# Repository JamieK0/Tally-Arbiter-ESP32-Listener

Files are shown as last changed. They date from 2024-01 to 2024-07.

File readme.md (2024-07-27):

# ESP32 Listener/Tally Light with OLED and Neopixels
An ESP32 listener for Tally Arbiter.
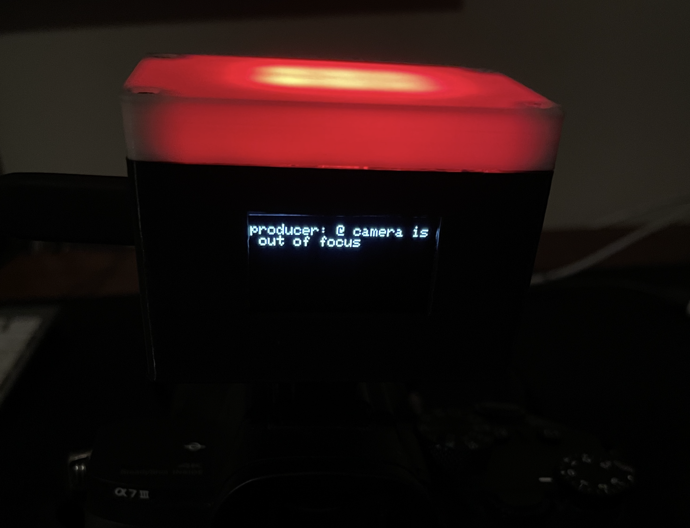
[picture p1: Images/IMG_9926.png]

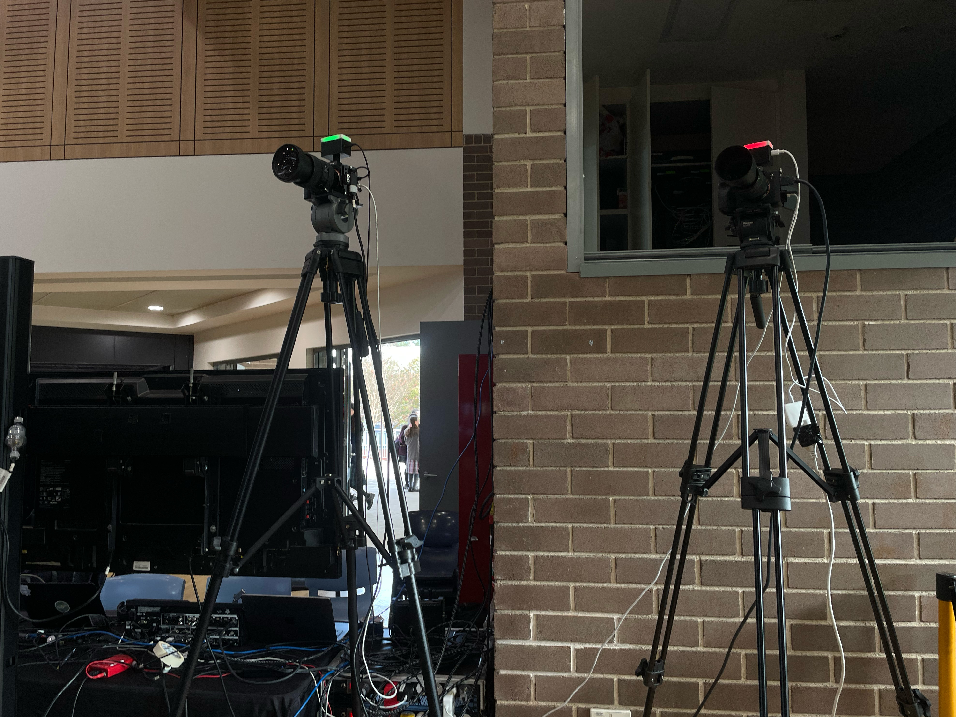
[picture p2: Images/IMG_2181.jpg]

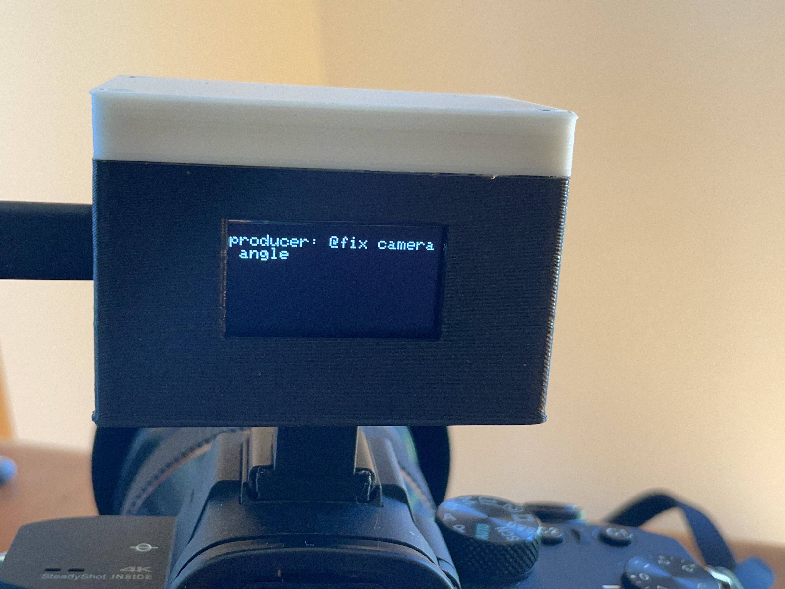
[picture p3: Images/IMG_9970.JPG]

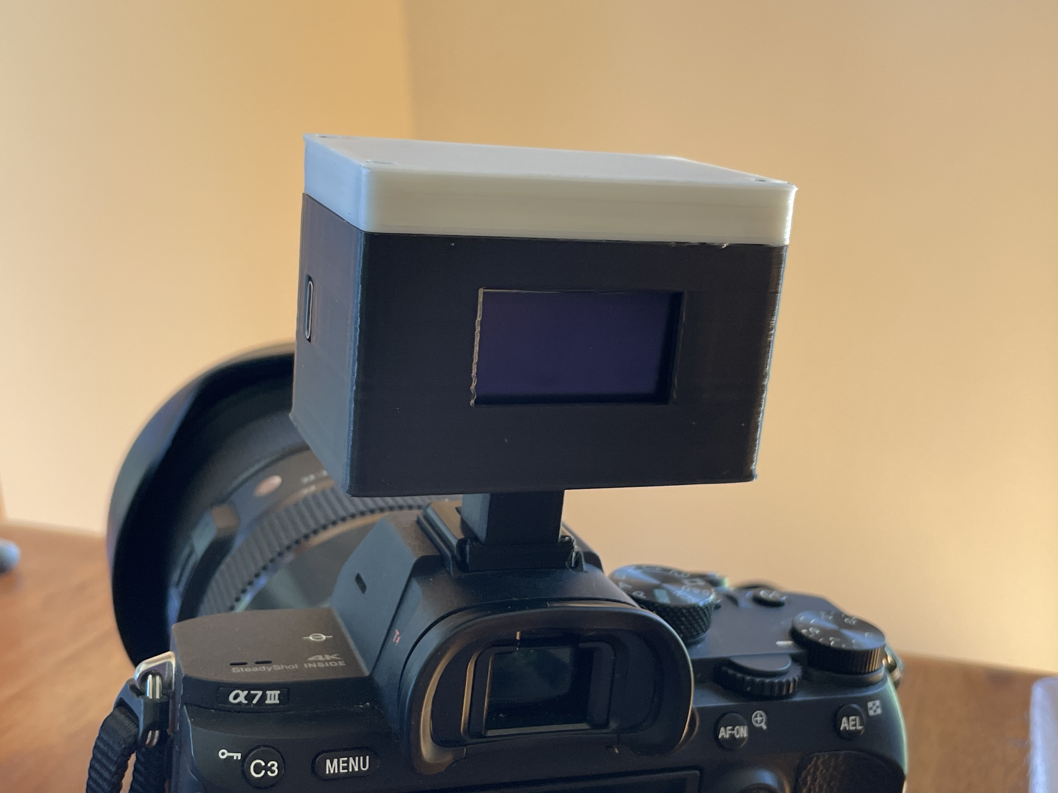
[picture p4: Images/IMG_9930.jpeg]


## Features
- Neopixel indicator lights for program and preview
- OLED screen for displaying messages
- Messages are sent to the OLED screen on the tally light unit by including "@" at the start of the message
- 3D printed case. CAD files are included
- Side and bottom attachment points for accessories. Coldshoe mount is included in the CAD files.

## Tally Arbiter

> A camera tally lights project capable of listening/fetching tally data from multiple sources or video switchers and arbitrating whether an end device is considered to be in Preview or Program. Supports many different switcher types and protocols as well as many types of tally output.

Learn more [here](https://github.com/josephdadams/TallyArbiter).

## Bill of materials
- ESP32 development board
- 1.3 inch i2c OLED screen
- 6x neopixel LEDs
- 14x M3 4mm length (OD 4.5mm) heated inserts
- 6x M3 16mm hex socket grubscrews
- Black PLA filament
- White PLA filament
- Insulated copper wires

## Tools
- 3D printer
- Soldering iron
- Hot glue gun
- Hex key set

## Installation

### 3D Printing
Use the seperate 3mf files in the CAD folder for printing.
I printed my case in PLA and it has been working fine.
The top piece is to be printed in white to act as diffusion for the LEDs.
#### Recommended print settings
- 3 permiters
- 15% infill for the bottom piece
- No infill or solid infill for the top piece. This is to ensure the LED diffusion is smooth.
- The coldshoe mount should be printed with the tally connector face facing the built plate. Supports may be needed.

### Wiring
| ESP32 | OLED | Neopixels |
|---|---|---|
| 3V | VCC  | 5V |
| GND | GND  | GND |
| D18 | | DIN |
| D21 | SCA  | |
| D22 | SCK  | |

### Programing the ESP32
Use the Ardunio IDE to program the ESP32. This [tutorial](https://randomnerdtutorials.com/installing-the-esp32-board-in-arduino-ide-windows-instructions/) is helpful for installing ESP32 boards in the IDE.
The Arduino IDE sketch file is in the esp32-neopixel-listener folder.

### Building the case
Use a soldering iron to melt the heated inserts into the holes in between the two parts of the case. Add heated inserts to the accessory attachment points as well.
The screen can be placed into its compartment. Use some hot glue to secure it in place if necessary.
The ESP32 can slide in on an angle before being pushed against the back of the case to hold it in place.
The neopixels sit above the ESP32.
Use the appropriately sized hex key to screw the grub screws into the heated inserts, attaching the two pieces of the case.

## Making your own accessories
Accessories can be connected using this template for the heated inserts alignment:
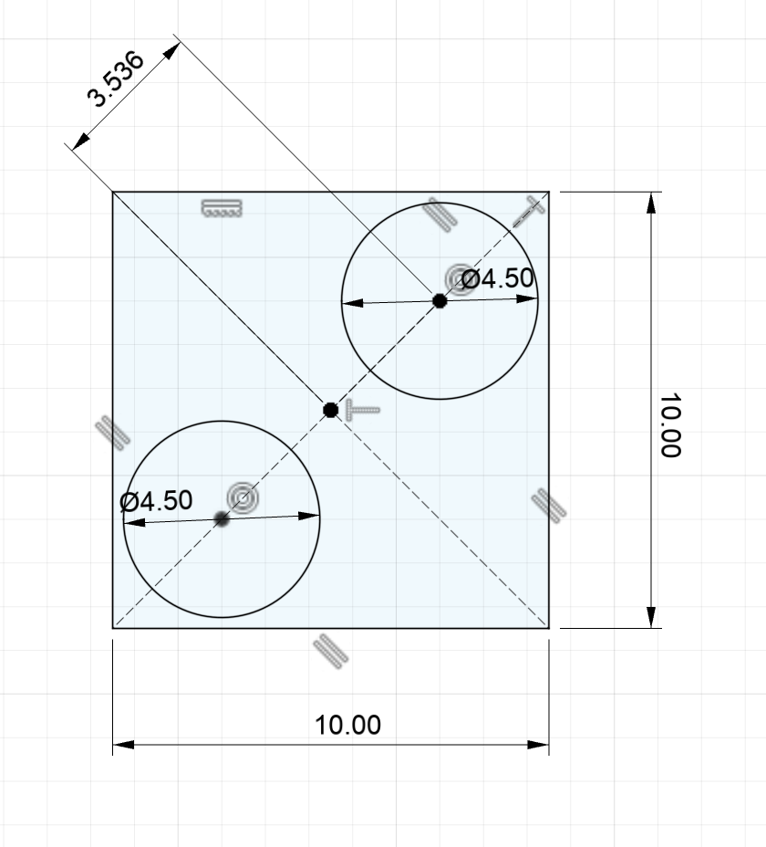
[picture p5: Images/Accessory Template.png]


## License
Distributed under the MIT License.

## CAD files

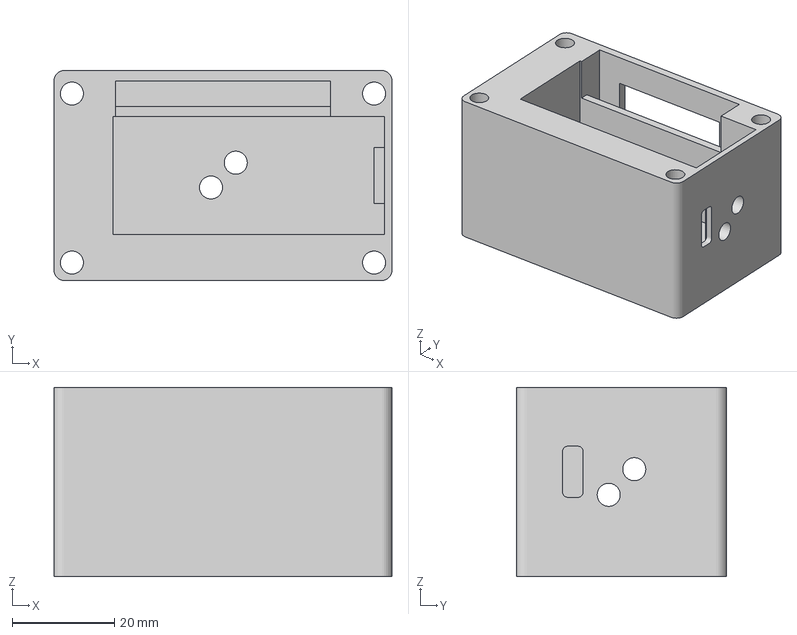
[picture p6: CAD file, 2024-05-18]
CAD/ESP32 Tally Case Bottom.3mf
66.0 x 41.0 x 37.0 mm

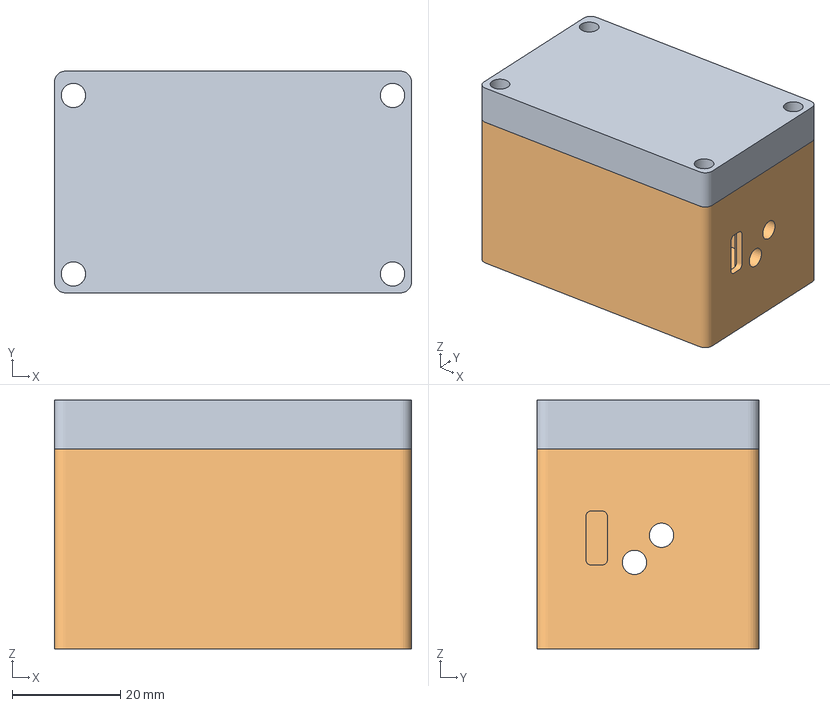
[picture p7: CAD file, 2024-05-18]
CAD/ESP32 Tally Case.3mf
66.0 x 41.0 x 46.0 mm

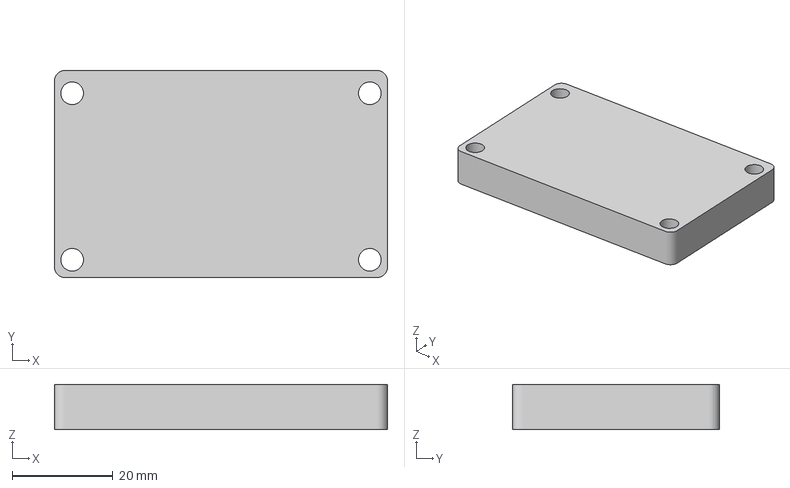
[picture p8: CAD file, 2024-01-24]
CAD/ESP32 Tally Case Top.3mf
66.0 x 41.0 x 9.00 mm

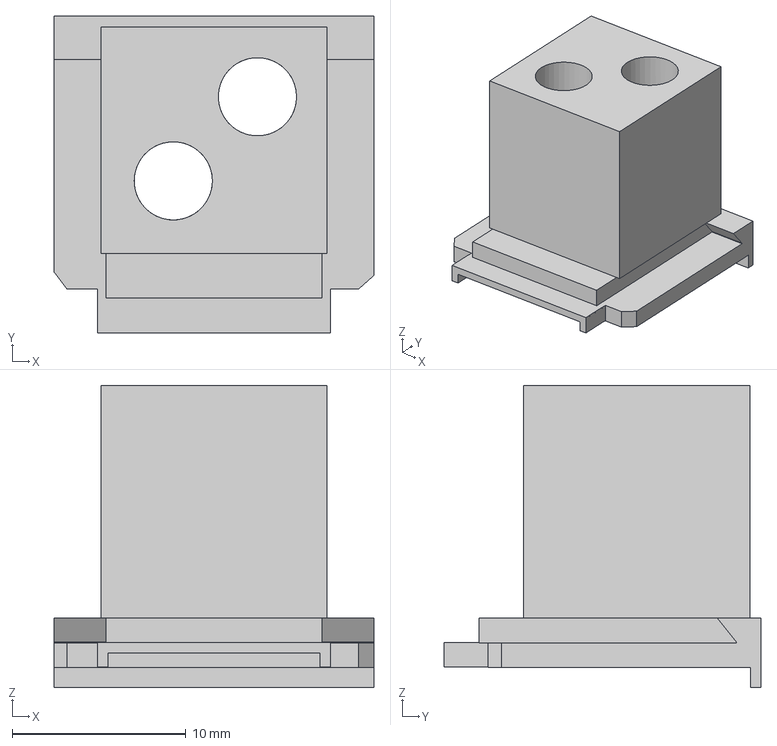
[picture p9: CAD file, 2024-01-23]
CAD/Coldshoe Mount.3mf
18.4 x 18.2 x 17.4 mm

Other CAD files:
CAD/Coldshoe Mount.f3d
CAD/ESP32 Tally Case.f3d

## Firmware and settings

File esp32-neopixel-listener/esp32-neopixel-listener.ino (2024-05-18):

#include <WebSocketsClient.h>
#include <SocketIOclient.h>
#include <Arduino_JSON.h>
#include <Adafruit_NeoPixel.h>
#include <WiFiManager.h>
#include <ArduinoOTA.h>
#include <ESPmDNS.h>
#include <Preferences.h>
#include <SPI.h>
#include <Wire.h>
#include <Adafruit_GFX.h>
#include <Adafruit_SH110X.h>
#include <Fonts/FreeSans9pt7b.h>

String listenerDeviceName = "neoPixel-1";

/* USER CONFIG VARIABLES
 *  Change the following variables before compiling and sending the code to your device.
 */
#define LED_PIN 18
#define BRIGHTNESS 255  // Set BRIGHTNESS to about 1/5 (max = 255)
#define LED_COUNT 6
#define maxTextSize 5  //larger sourceName text
// Declare our NeoPixel strip object:
Adafruit_NeoPixel strip(LED_COUNT, LED_PIN, NEO_GRB + NEO_KHZ800);
// Argument 1 = Number of pixels in NeoPixel strip
// Argument 2 = Arduino pin number (most are valid)
// Argument 3 = Pixel type flags, add together as needed:
//   NEO_KHZ800  800 KHz bitstream (most NeoPixel products w/WS2812 LEDs)
//   NEO_KHZ400  400 KHz (classic 'v1' (not v2) FLORA pixels, WS2811 drivers)
//   NEO_GRB     Pixels are wired for GRB bitstream (most NeoPixel products)
//   NEO_RGB     Pixels are wired for RGB bitstream (v1 FLORA pixels, not v2)
//   NEO_RGBW    Pixels are wired for RGBW bitstream (NeoPixel RGBW products)

#define TALLY_EXTRA_OUTPUT false

#if TALLY_EXTRA_OUTPUT
const int led_program = 10;
const int led_preview = 26;  //OPTIONAL Led for preview on pin G26
const int led_aux = 36;      //OPTIONAL Led for aux on pin G36
#endif

bool LAST_MSG = true;  // true = show log on tally screen

//Tally Arbiter Server
char tallyarbiter_host[40] = "192.168.0.20";  //IP address of the Tally Arbiter Server
char tallyarbiter_port[6] = "4455";

/* END OF USER CONFIG */

// OLED Config
/* Uncomment the initialize the I2C address , uncomment only one, If you get a totally blank screen try the other*/
#define i2c_Address 0x3c  //initialize with the I2C addr 0x3C Typically eBay OLED's
//#define i2c_Address 0x3d //initialize with the I2C addr 0x3D Typically Adafruit OLED's
#define SCREEN_WIDTH 128  // OLED display width, in pixels
#define SCREEN_HEIGHT 64  // OLED display height, in pixels
#define OLED_RESET -1     //   QT-PY / XIAO
Adafruit_SH1106G display = Adafruit_SH1106G(SCREEN_WIDTH, SCREEN_HEIGHT, &Wire, OLED_RESET);


Preferences preferences;

String prevType = "";  // reduce display flicker by storing previous state

String actualType = "";
String actualColor = "";
int actualPriority = 0;

//Tally Arbiter variables
SocketIOclient socket;
JSONVar BusOptions;
JSONVar Devices;
JSONVar DeviceStates;
String DeviceId = "unassigned";
String DeviceName = "Unassigned";
String LastMessage = "";

//General Variables
bool networkConnected = false;

#define WHITE strip.Color(255, 255, 255)
#define BLACK strip.Color(0, 0, 0)

WiFiManager wm;                     // global wm instance
WiFiManagerParameter custom_field;  // global param ( for non blocking w params )

void setup() {
  Serial.begin(115200);
  while (!Serial)
    ;

  // Initialize the ESP32 object
  logger("Initializing ESP32.", "info-quiet");

  setCpuFrequencyMhz(80);  //Save battery by turning down the CPU clock
  btStop();                //Save battery by turning off BlueTooth

  uint64_t chipid = ESP.getEfuseMac();
  listenerDeviceName = "neoPixel-" + String((uint16_t)(chipid >> 32)) + String((uint32_t)chipid);

  strip.begin();  // INITIALIZE NeoPixel strip object (REQUIRED)
  strip.show();   // Turn OFF all pixels ASAP
  strip.setBrightness(BRIGHTNESS);
  setColor(strip.Color(0, 0, 255));
  logger("Listener device name: " + listenerDeviceName, "info");

  preferences.begin("tally-arbiter", false);

  // added to clear out corrupt prefs
  //preferences.clear();
  logger("Reading preferences", "info-quiet");
  if (preferences.getString("deviceid").length() > 0) {
    DeviceId = preferences.getString("deviceid");
  }
  if (preferences.getString("devicename").length() > 0) {
    DeviceName = preferences.getString("devicename");
  }
  if (preferences.getString("taHost").length() > 0) {
    String newHost = preferences.getString("taHost");
    logger("Setting TallyArbiter host as" + newHost, "info-quiet");
    newHost.toCharArray(tallyarbiter_host, 40);
  }
  if (preferences.getString("taPort").length() > 0) {
    String newPort = preferences.getString("taPort");
    logger("Setting TallyArbiter port as" + newPort, "info-quiet");
    newPort.toCharArray(tallyarbiter_port, 6);
  }

  preferences.end();

  delay(100);          //wait 100ms before moving on
  connectToNetwork();  //starts Wifi connection
  while (!networkConnected) {
    delay(200);
  }

  ArduinoOTA.setHostname(listenerDeviceName.c_str());
  ArduinoOTA.setPassword("tallyarbiter");
  ArduinoOTA
    .onStart([]() {
      String type;
      if (ArduinoOTA.getCommand() == U_FLASH)
        type = "sketch";
      else  // U_SPIFFS
        type = "filesystem";

      // NOTE: if updating SPIFFS this would be the place to unmount SPIFFS using SPIFFS.end()
      Serial.println("Start updating " + type);
    })
    .onEnd([]() {
      Serial.println("\nEnd");
    })
    .onProgress([](unsigned int progress, unsigned int total) {
      Serial.printf("Progress: %u%%\r", (progress / (total / 100)));
    })
    .onError([](ota_error_t error) {
      Serial.printf("Error[%u]: ", error);
      if (error == OTA_AUTH_ERROR) logger("Auth Failed", "error");
      else if (error == OTA_BEGIN_ERROR) logger("Begin Failed", "error");
      else if (error == OTA_CONNECT_ERROR) logger("Connect Failed", "error");
      else if (error == OTA_RECEIVE_ERROR) logger("Receive Failed", "error");
      else if (error == OTA_END_ERROR) logger("End Failed", "error");
    });

  ArduinoOTA.begin();


  // OLED setup:
  display.begin(i2c_Address, true);
  display.display();
  delay(2000);
  // Clear the buffer.
  display.clearDisplay();
  display.setTextSize(1);
  display.setTextColor(SH110X_WHITE);
  display.setCursor(0, 1);
  display.println("Tally Arbiter");
  display.println("developed by Joseph");
  display.println("Adams.");
  display.println("ESP32 Tally");
  display.println("developed by Jamie K.");
  display.println("Distributed under the");
  display.println("MIT License");

  display.display();
  display.clearDisplay();

#if TALLY_EXTRA_OUTPUT
  // Enable interal led for program trigger
  pinMode(led_program, OUTPUT);
  digitalWrite(led_program, HIGH);
  pinMode(led_preview, OUTPUT);
  digitalWrite(led_preview, HIGH);
  pinMode(led_aux, OUTPUT);
  digitalWrite(led_aux, HIGH);
#endif
  connectToServer();
}

void loop() {
  ArduinoOTA.handle();
  socket.loop();
}

void showDeviceInfo() {
  //displays the currently assigned device and tally data
  evaluateMode();
}

void logger(String strLog, String strType) {
  Serial.println(strLog);
  /*
  if (strType == "info") {
    Serial.println(strLog);
  } else {
    Serial.println(strLog);
  }
  */
}

void connectToNetwork() {
  WiFi.mode(WIFI_STA);  // explicitly set mode, esp defaults to STA+AP

  logger("Connecting to SSID: " + String(WiFi.SSID()), "info");

  //reset settings - wipe credentials for testing
  //wm.resetSettings();

  //const char* custom_radio_str = "<br/><label for='taHostIP'>Tally Arbiter Server</label><input type='text' name='taHostIP'>";
  //new (&custom_field) WiFiManagerParameter(custom_radio_str); // custom html input

  WiFiManagerParameter custom_taServer("taHostIP", "Tally Arbiter Server", tallyarbiter_host, 40);
  WiFiManagerParameter custom_taPort("taHostPort", "Port", tallyarbiter_port, 6);

  wm.addParameter(&custom_taServer);
  wm.addParameter(&custom_taPort);

  //wm.addParameter(&custom_field);
  wm.setSaveParamsCallback(saveParamCallback);

  // custom menu via array or vector
  std::vector<const char *> menu = { "wifi", "param", "info", "sep", "restart", "exit" };
  wm.setMenu(menu);

  // set dark theme
  wm.setClass("invert");

  wm.setConfigPortalTimeout(120);  // auto close configportal after n seconds

  bool res;

  res = wm.autoConnect(listenerDeviceName.c_str());  // AP name for setup

  if (!res) {
    logger("Failed to connect", "error");
    // ESP.restart();
  } else {
    //if you get here you have connected to the WiFi
    logger("connected...yay :)", "info");
    networkConnected = true;

    //TODO: fix MDNS discovery
    /*
    int nrOfServices = MDNS.queryService("tally-arbiter", "tcp");

    if (nrOfServices == 0) {
      logger("No server found.", "error");
    } else {
      logger("Number of servers found: ", "info");
      Serial.print(nrOfServices);
     
      for (int i = 0; i < nrOfServices; i=i+1) {
 
        Serial.println("---------------");
       
        Serial.print("Hostname: ");
        Serial.println(MDNS.hostname(i));
 
        Serial.print("IP address: ");
        Serial.println(MDNS.IP(i));
 
        Serial.print("Port: ");
        Serial.println(MDNS.port(i));
 
        Serial.println("---------------");
      }
    }
    */
  }
}

String getParam(String name) {
  //read parameter from server, for customhmtl input
  String value;
  if (wm.server->hasArg(name)) {
    value = wm.server->arg(name);
  }
  return value;
}


void saveParamCallback() {
  logger("[CALLBACK] saveParamCallback fired", "info-quiet");
  logger("PARAM tally Arbiter Server = " + getParam("taHostIP"), "info-quiet");
  String str_taHost = getParam("taHostIP");
  String str_taPort = getParam("taHostPort");

  //str_taHost.toCharArray(tallyarbiter_host, 40);
  //saveEEPROM();
  logger("Saving new TallyArbiter host", "info-quiet");
  logger(str_taHost, "info-quiet");
  preferences.begin("tally-arbiter", false);
  preferences.putString("taHost", str_taHost);
  preferences.putString("taPort", str_taPort);
  preferences.end();
}

void WiFiEvent(WiFiEvent_t event) {
  switch (event) {
    case SYSTEM_EVENT_STA_GOT_IP:
      logger("Network connected!", "info");
      logger(WiFi.localIP().toString(), "info");
      networkConnected = true;
      break;
    case SYSTEM_EVENT_STA_DISCONNECTED:
      logger("Network connection lost!", "info");
      networkConnected = false;
      break;
    default:
      break;
  }
}

void ws_emit(String event, const char *payload = NULL) {
  if (payload) {
    String msg = "[\"" + event + "\"," + payload + "]";
    //Serial.println(msg);
    socket.sendEVENT(msg);
  } else {
    String msg = "[\"" + event + "\"]";
    //Serial.println(msg);
    socket.sendEVENT(msg);
  }
}

void connectToServer() {
  logger("Connecting to Tally Arbiter host: " + String(tallyarbiter_host), "info");
  socket.onEvent(socket_event);
  socket.begin(tallyarbiter_host, atol(tallyarbiter_port));
}

void socket_event(socketIOmessageType_t type, uint8_t *payload, size_t length) {
  switch (type) {
    case sIOtype_CONNECT:
      socket_Connected((char *)payload, length);
      break;

    case sIOtype_DISCONNECT:
    case sIOtype_ACK:
    case sIOtype_ERROR:
    case sIOtype_BINARY_EVENT:
    case sIOtype_BINARY_ACK:
      // Not handled
      break;

    case sIOtype_EVENT:
      String msg = (char *)payload;
      String type = msg.substring(2, msg.indexOf("\"", 2));
      String content = msg.substring(type.length() + 4);
      content.remove(content.length() - 1);

      logger("Got event '" + type + "', data: " + content, "info-quiet");

      if (type == "bus_options") BusOptions = JSON.parse(content);
      if (type == "reassign") socket_Reassign(content);
      if (type == "flash") socket_Flash();
      if (type == "messaging") socket_Messaging(content);

      if (type == "deviceId") {
        DeviceId = content.substring(1, content.length() - 1);
        SetDeviceName();
        showDeviceInfo();
      }

      if (type == "devices") {
        Devices = JSON.parse(content);
        SetDeviceName();
      }

      if (type == "device_states") {
        DeviceStates = JSON.parse(content);
        processTallyData();
      }

      break;
  }
}

void socket_Connected(const char *payload, size_t length) {
  logger("Connected to Tally Arbiter server.", "info");
  logger("DeviceId: " + DeviceId, "info-quiet");
  String deviceObj = "{\"deviceId\": \"" + DeviceId + "\", \"listenerType\": \"" + listenerDeviceName.c_str() + "\", \"canBeReassigned\": true, \"canBeFlashed\": true, \"supportsChat\": true }";
  char charDeviceObj[1024];
  strcpy(charDeviceObj, deviceObj.c_str());
  ws_emit("listenerclient_connect", charDeviceObj);
}

void socket_Flash() {
  //flash the pixel array white 3 times
  strip.setBrightness(255);
  setColor(WHITE);
  delay(500);
  setColor(BLACK);
  delay(500);
  setColor(WHITE);
  delay(500);
  setColor(BLACK);
  delay(500);
  setColor(WHITE);
  delay(500);
  setColor(BLACK);
  strip.setBrightness(BRIGHTNESS);

  showDeviceInfo();
}

void setColor(uint32_t color) {
  for (int i = 0; i < strip.numPixels(); i++) {  // For each pixel in strip...
    strip.setPixelColor(i, color);               //  Set pixel's color (in RAM)
    strip.show();                                //  Update strip to match
  }
}

String strip_quot(String str) {
  if (str[0] == '"') {
    str.remove(0, 1);
  }
  if (str.endsWith("\"")) {
    str.remove(str.length() - 1, 1);
  }
  return str;
}

void socket_Reassign(String payload) {
  String oldDeviceId = payload.substring(0, payload.indexOf(','));
  String newDeviceId = payload.substring(oldDeviceId.length() + 1);
  newDeviceId = newDeviceId.substring(0, newDeviceId.indexOf(','));
  oldDeviceId = strip_quot(oldDeviceId);
  newDeviceId = strip_quot(newDeviceId);

  String reassignObj = "{\"oldDeviceId\": \"" + oldDeviceId + "\", \"newDeviceId\": \"" + newDeviceId + "\"}";
  char charReassignObj[1024];
  strcpy(charReassignObj, reassignObj.c_str());
  ws_emit("listener_reassign_object", charReassignObj);
  ws_emit("devices");
  setColor(WHITE);
  delay(200);
  setColor(BLACK);
  delay(200);
  setColor(WHITE);
  delay(200);
  setColor(BLACK);
  logger("newDeviceId: " + newDeviceId, "info-quiet");
  DeviceId = newDeviceId;
  preferences.begin("tally-arbiter", false);
  preferences.putString("deviceid", newDeviceId);
  preferences.end();
  SetDeviceName();
}

void socket_Messaging(String payload) {
  String strPayload = String(payload);
  int typeQuoteIndex = strPayload.indexOf(',');
  String messageType = strPayload.substring(0, typeQuoteIndex);
  messageType.replace("\"", "");
  int messageQuoteIndex = strPayload.lastIndexOf(',');
  String message = strPayload.substring(messageQuoteIndex + 1);
  message.replace("\"", "");
  LastMessage = messageType + ": " + message;
  evaluateMode();
}

void processTallyData() {
  bool typeChanged = false;
  for (int i = 0; i < DeviceStates.length(); i++) {
    if (DeviceStates[i]["sources"].length() > 0) {
      typeChanged = true;
      actualType = getBusTypeById(JSON.stringify(DeviceStates[i]["busId"]));
      actualColor = getBusColorById(JSON.stringify(DeviceStates[i]["busId"]));
      actualPriority = getBusPriorityById(JSON.stringify(DeviceStates[i]["busId"]));
    }
  }
  if (!typeChanged) {
    actualType = "";
    actualColor = "";
    actualPriority = 0;
  }
  evaluateMode();
}

String getBusTypeById(String busId) {
  for (int i = 0; i < BusOptions.length(); i++) {
    if (JSON.stringify(BusOptions[i]["id"]) == busId) {
      return JSON.stringify(BusOptions[i]["type"]);
    }
  }

  return "invalid";
}

String getBusColorById(String busId) {
  for (int i = 0; i < BusOptions.length(); i++) {
    if (JSON.stringify(BusOptions[i]["id"]) == busId) {
      return JSON.stringify(BusOptions[i]["color"]);
    }
  }

  return "invalid";
}

int getBusPriorityById(String busId) {
  for (int i = 0; i < BusOptions.length(); i++) {
    if (JSON.stringify(BusOptions[i]["id"]) == busId) {
      return (int)JSON.stringify(BusOptions[i]["priority"]).toInt();
    }
  }

  return 0;
}

void SetDeviceName() {
  for (int i = 0; i < Devices.length(); i++) {
    if (JSON.stringify(Devices[i]["id"]) == "\"" + DeviceId + "\"") {
      String strDevice = JSON.stringify(Devices[i]["name"]);
      DeviceName = strDevice.substring(1, strDevice.length() - 1);
      break;
    }
  }
  preferences.begin("tally-arbiter", false);
  preferences.putString("devicename", DeviceName);
  preferences.end();
  evaluateMode();
}

void evaluateMode() {
  if (actualType != prevType) {
    actualColor.replace("#", "");
    String hexstring = actualColor;
    long number = (long)strtol(&hexstring[1], NULL, 16);
    int r = number >> 16;
    int g = number >> 8 & 0xFF;
    int b = number & 0xFF;
    if (actualType != "") {
      setColor(strip.Color(r, g, b));
    } else {
      setColor(BLACK);
    }

#if TALLY_EXTRA_OUTPUT
    if (actualType == "preview") {
      digitalWrite(led_program, HIGH);
      digitalWrite(led_preview, LOW);
      digitalWrite(led_aux, LOW);
    } else if (actualType == "preview") {
      digitalWrite(led_program, LOW);
      digitalWrite(led_preview, HIGH);
      digitalWrite(led_aux, LOW);
    } else if (actualType == "aux") {
      digitalWrite(led_program, LOW);
      digitalWrite(led_preview, LOW);
      digitalWrite(led_aux, HIGH);
    } else {
      digitalWrite(led_program, LOW);
      digitalWrite(led_preview, LOW);
      digitalWrite(led_aux, LOW);
    }
#endif

    logger("Device is in " + actualType + " (color " + actualColor + " r: " + String(r) + " g: " + String(g) + " b: " + String(b) + " - priority " + String(actualPriority) + ")", "info");

    prevType = actualType;
  }
  if (LAST_MSG == true) {    
   if (LastMessage.indexOf('@') >= 0) { // Only sends message if it contains @. Means that the tally only receives directions and not conversations or replies in the messages system.
    display.clearDisplay();
    display.setCursor(0, 1);
    display.setTextColor(SH110X_WHITE);
    display.println(LastMessage);
    Serial.println(LastMessage);
    display.display();
   }
  }
}

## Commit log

2024-01-22 For ESP32 neopixel
2024-01-22 Correct structure for Arduino IDE
    [esp32-neopixel-listener.ino]
2024-01-23 Add CAD files
    [Coldshoe Mount.3mf, ESP32 Tally Case.3mf, ESP32 Tally Case.f3d]
2024-01-23 Create ESP32 Tally Case Bottom.3mf
    [ESP32 Tally Case Bottom.3mf]
2024-01-24 Add CAD
    [Coldshoe Mount.f3d, ESP32 Tally Case Top.3mf, ESP32 Tally Case.3mf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]
2024-05-18 Update CAD files
    [ESP32 Tally Case Bottom.3mf, ESP32 Tally Case.f3d]
2024-05-18 Update CAD
    [ESP32 Tally Case Bottom.3mf, ESP32 Tally Case.3mf, ESP32 Tally Case.f3d]
